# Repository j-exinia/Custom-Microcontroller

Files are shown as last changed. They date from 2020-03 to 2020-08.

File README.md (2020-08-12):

# Microcontroller Breakout Board

## Block Diagram

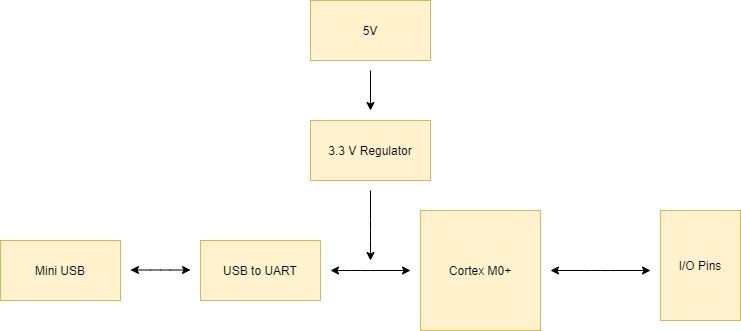
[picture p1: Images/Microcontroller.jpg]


## Peripherals 

### Microprocessor 

* [ARM Cortex M0+](https://www.mouser.com/datasheet/2/389/dm00613881-1799439.pdf)

### USB Mini Port

* [UJ2-MBH](https://www.mouser.com/datasheet/2/670/uj2-mbh-smt-1313286.pdf)

### USB to UART

* [FT230XS-R](https://www.mouser.com/datasheet/2/163/DS_FT230X-5395.pdf)

### Voltage Regulator

* [TPS77733DR](http://www.ti.com/lit/ds/symlink/tps777.pdf)

## Images
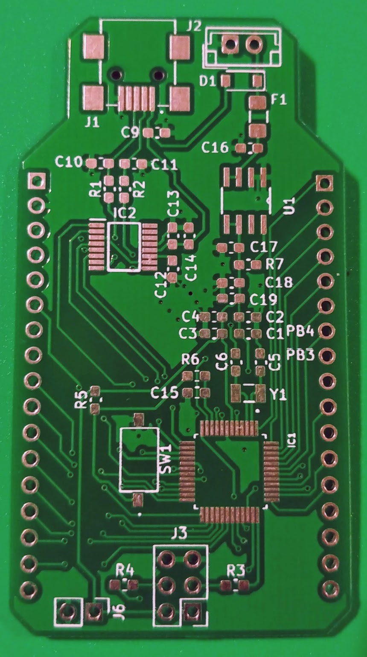
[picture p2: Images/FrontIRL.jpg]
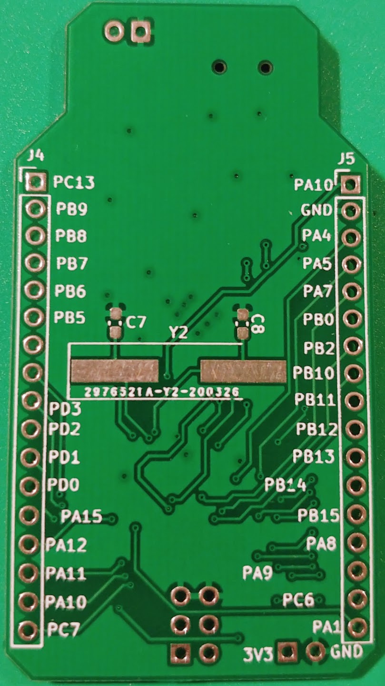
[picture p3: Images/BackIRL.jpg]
, 

## Designers

* **Jorge Exinia** - *PCB design* - [j-exinia](https://github.com/j-exinia)

### Built With

* [KiCad](https://kicad-pcb.org/) - The PCB design software used

### Errata

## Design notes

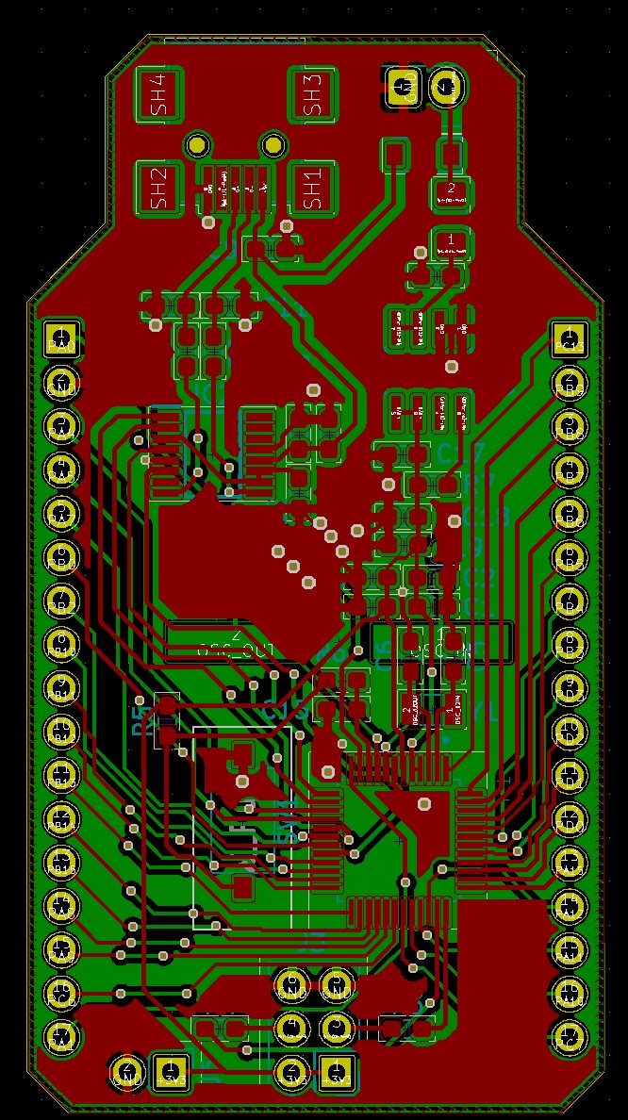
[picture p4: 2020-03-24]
Images/Combined.jpg

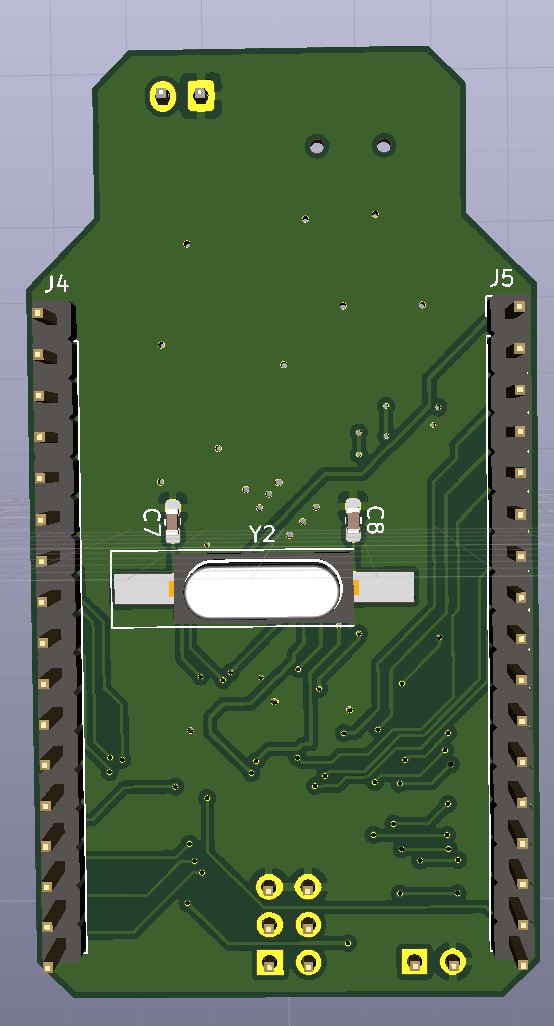
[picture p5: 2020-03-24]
Images/3dViewBottom.jpg

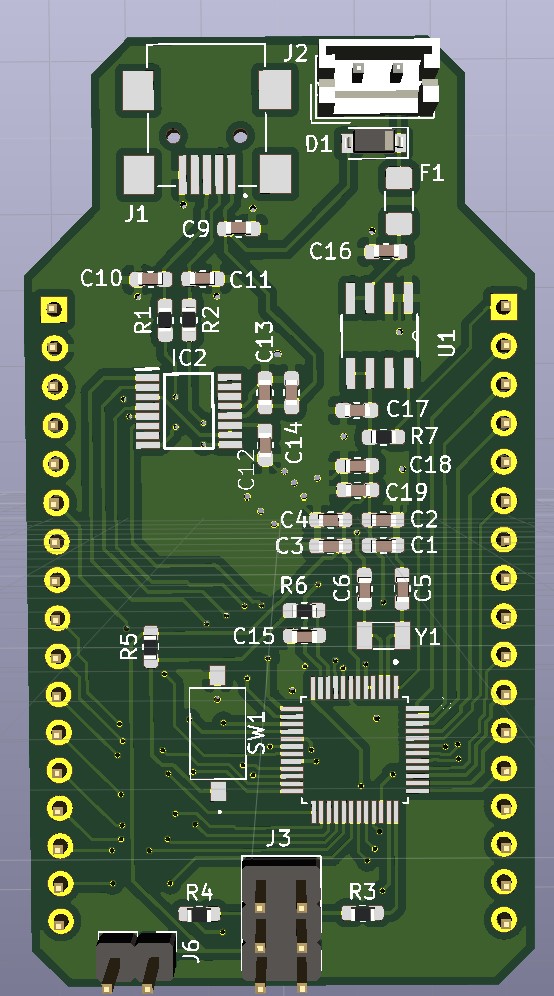
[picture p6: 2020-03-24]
Images/3dView.jpg

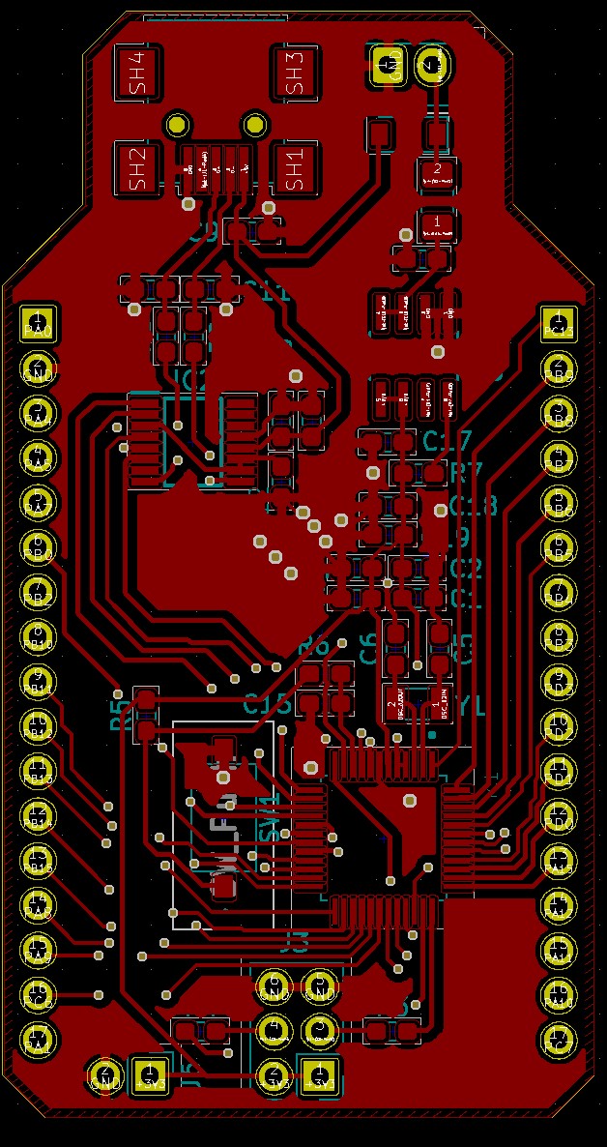
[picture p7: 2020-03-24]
Images/TopLayer .jpg

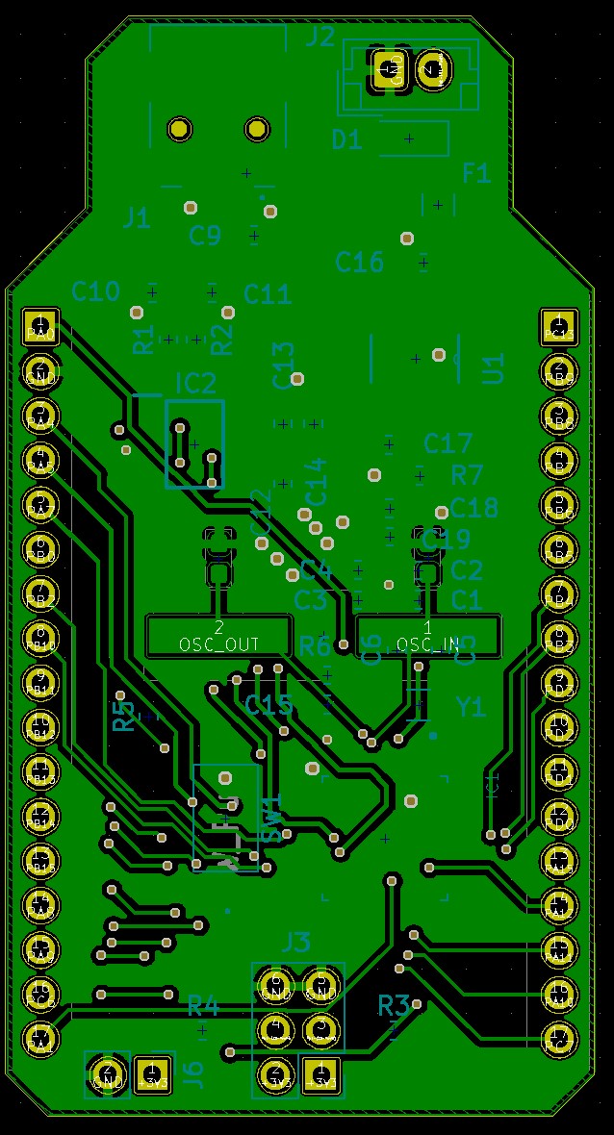
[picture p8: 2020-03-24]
Images/BottomLayer .jpg

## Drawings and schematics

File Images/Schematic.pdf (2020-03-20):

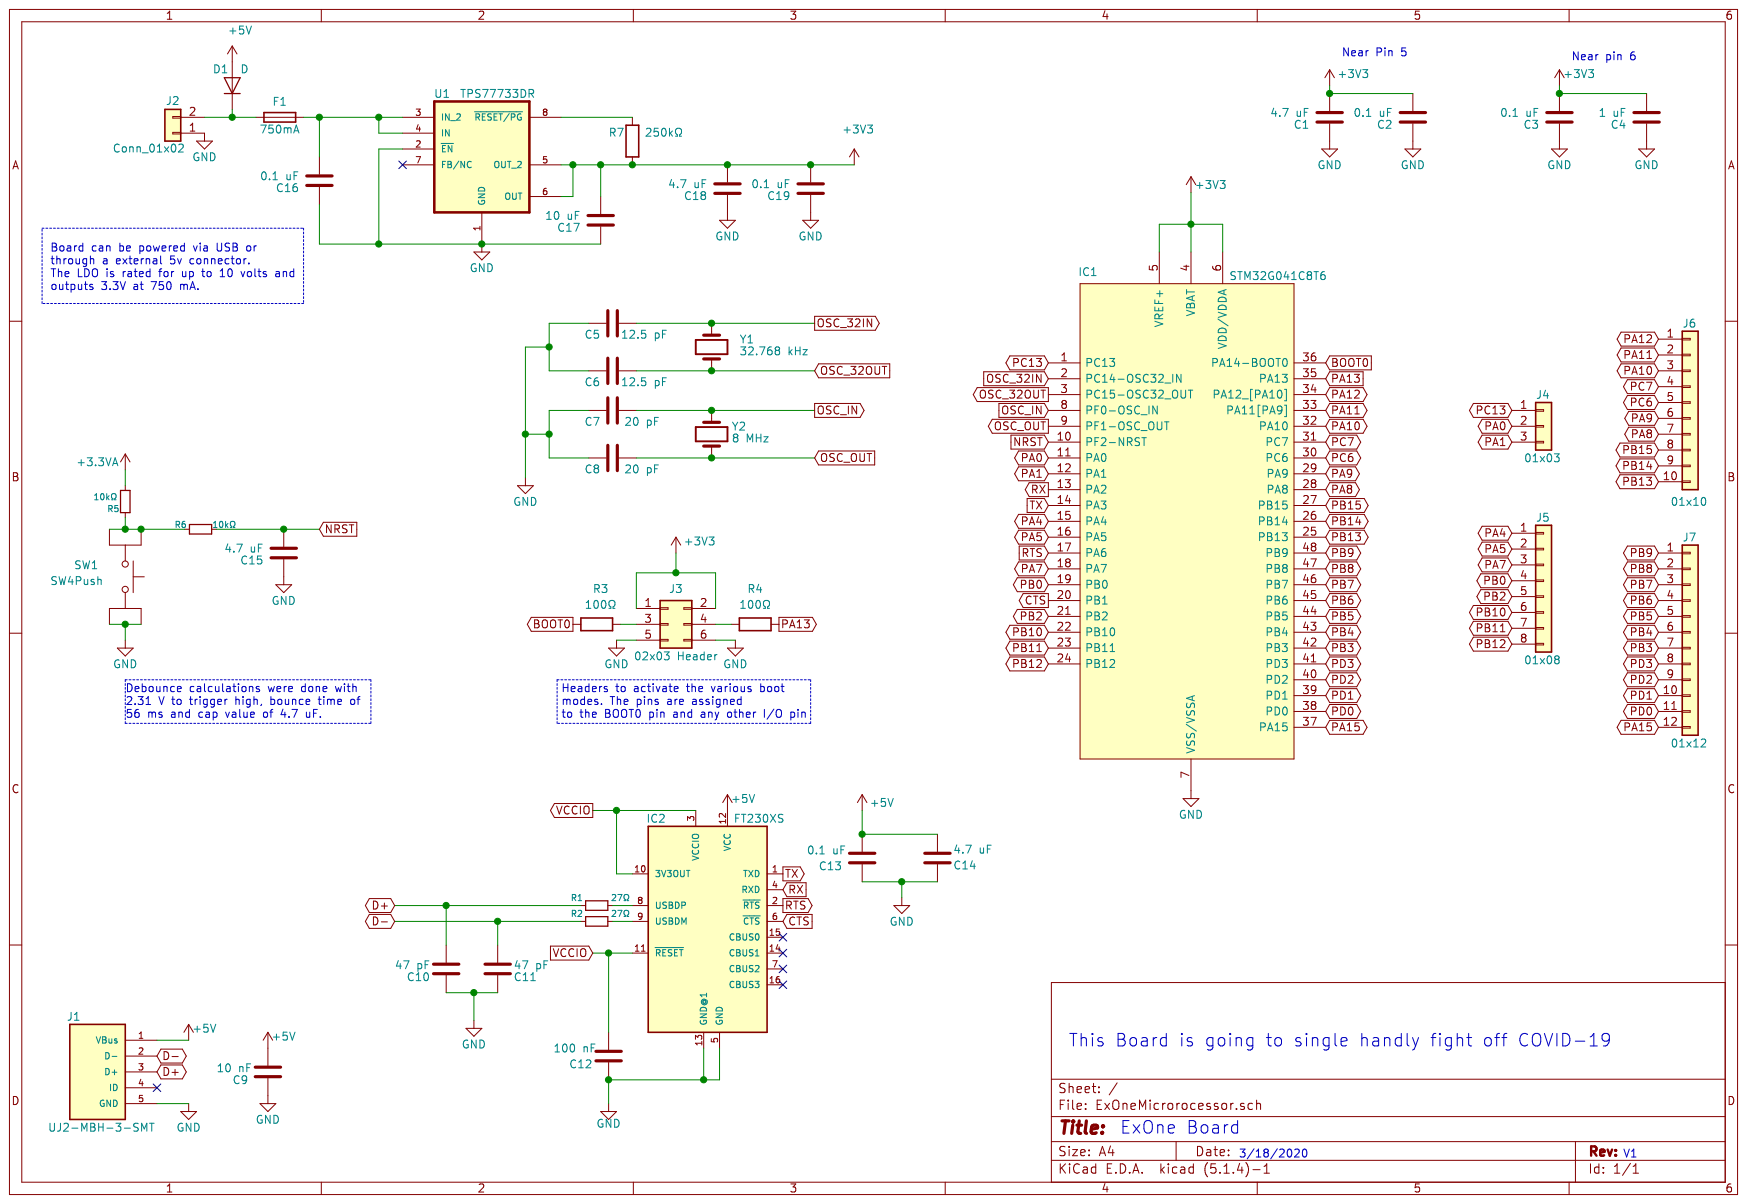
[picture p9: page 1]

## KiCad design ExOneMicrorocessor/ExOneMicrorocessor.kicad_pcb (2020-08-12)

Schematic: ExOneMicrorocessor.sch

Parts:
C1, C14, C15, C18: 4.7 uF; C_0603_1608Metric_Pad1.05x0.95mm_HandSolder
C2, C3, C12, C13, C16, C19: 0.1 uF; C_0603_1608Metric_Pad1.05x0.95mm_HandSolder
C4: 1 uF; C_0603_1608Metric_Pad1.05x0.95mm_HandSolder
C5, C6: 12.5 pF; C_0603_1608Metric_Pad1.05x0.95mm_HandSolder
C7, C8: 20 pF; C_0603_1608Metric_Pad1.05x0.95mm_HandSolder
C9: 0.01 uF; C_0603_1608Metric_Pad1.05x0.95mm_HandSolder
C10, C11: 47 pF; C_0603_1608Metric_Pad1.05x0.95mm_HandSolder
C17: 10 uF; C_0603_1608Metric_Pad1.05x0.95mm_HandSolder
D1: D; D_SOD-123
F1: 750mA; Fuse_1206_3216Metric_Pad1.42x1.75mm_HandSolder
IC1: STM32G041C8T6; STM32G041C8; Mouser Part Number 511-STM32G041C8T6
IC2: FT230XS
J1: UJ2-MBH-3-SMT; UJ2-MBH-SMT
J2: Conn_01x02; JST_EH_B2B-EH-A_1x02_P2.50mm_Vertical
J3: 02x03 Header; PinHeader_2x03_P2.54mm_Vertical
J4, J5: Conn_01x17; PinHeader_1x17_P2.54mm_Vertical
J6: Conn_01x02; PinHeader_1x02_P2.54mm_Vertical
R1, R2: 27Ω; R_0603_1608Metric_Pad1.05x0.95mm_HandSolder
R3, R4: 100Ω; R_0603_1608Metric_Pad1.05x0.95mm_HandSolder
R5, R6: 10kΩ; R_0603_1608Metric_Pad1.05x0.95mm_HandSolder
R7: 250kΩ; R_0603_1608Metric_Pad1.05x0.95mm_HandSolder
SW1: SW_Push; PTS636SM25SMTRLFS
U1: TPS77733DR; TPS77733
Y1: 32.768 kHz; Crystal_SMD_3215-2Pin_3.2x1.5mm
Y2: 8 MHz; Crystal_SMD_HC49-SD_HandSoldering

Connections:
3VLn: C12.1, IC2.3 (VCCIO), IC2.10 (3V3OUT), IC2.11 (~RESET~)
+3V3: C1.2, C2.2, C3.2, C4.2, C17.2, C18.2, C19.2, IC1.4 (VBAT), IC1.5 (VREF+), IC1.6 (VDD/VDDA), J3.1, J3.2, J6.1, R5.2, R7.1, U1.5 (OUT_2), U1.6 (OUT)
+5V: C9.1, C13.1, C14.2, D1.2 (A), IC2.12 (VCC), J1.1 (VBus)
BOOT0: IC1.36 (PA14-BOOT0), R3.2
CTS: IC1.20 (PB1), IC2.6 (~CTS~)
D+: C10.1, J1.3 (D+), R1.2
D-: C11.1, J1.2 (D-), R2.2
GND: C1.1, C2.1, C3.1, C4.1, C5.1, C6.1, C7.1, C8.1, C9.2, C10.2, C11.2, C12.2, C13.2, C14.1, C15.1, C16.1, C17.1, C18.1, C19.1, IC1.7 (VSS/VSSA), IC2.5 (GND), IC2.13 (GND@1), J1.5 (GND), J2.1, J3.5, J3.6, J5.2, J6.2, SW1.2, U1.1 (GND), U1.2 (~EN)
NRST: C15.2, IC1.10 (PF2-NRST), R6.2
unnamed: C16.2, F1.1, U1.3 (IN_2), U1.4 (IN)
unnamed: D1.1 (K), F1.2, J2.2
unnamed: IC2.8 (USBDP), R1.1
unnamed: IC2.9 (USBDM), R2.1
unnamed: J3.3, R3.1
unnamed: J3.4, R4.2
unnamed: R5.1, R6.1, SW1.1
unnamed: R7.2, U1.8 (~RESET/PG)
OSC_32IN: C5.2, IC1.2 (PC14-OSC32_IN), Y1.1
OSC_32OUT: C6.2, IC1.3 (PC15-OSC32_OUT), Y1.2
OSC_IN: C7.2, IC1.8 (PF0-OSC_IN), Y2.1
OSC_OUT: C8.2, IC1.9 (PF1-OSC_OUT), Y2.2
PA0: IC1.11 (PA0), J5.1
PA1: IC1.12 (PA1), J5.17
PA4: IC1.15 (PA4), J5.3
PA5: IC1.16 (PA5), J5.4
PA7: IC1.18 (PA7), J5.5
PA8: IC1.28 (PA8), J5.14
PA9: IC1.29 (PA9), J5.15
PA10: IC1.32 (PA10), J4.16
PA11: IC1.33 (PA11[PA9]), J4.15
PA12: IC1.34 (PA12_[PA10]), J4.14
PA13: IC1.35 (PA13), R4.1
PA15: IC1.37 (PA15), J4.13
PB0: IC1.19 (PB0), J5.6
PB2: IC1.21 (PB2), J5.7
PB3: IC1.42 (PB3), J4.8
PB4: IC1.43 (PB4), J4.7
PB5: IC1.44 (PB5), J4.6
PB6: IC1.45 (PB6), J4.5
PB7: IC1.46 (PB7), J4.4
PB8: IC1.47 (PB8), J4.3
PB9: IC1.48 (PB9), J4.2
PB10: IC1.22 (PB10), J5.8
PB11: IC1.23 (PB11), J5.9
PB12: IC1.24 (PB12), J5.10
PB13: IC1.25 (PB13), J5.11
PB14: IC1.26 (PB14), J5.12
PB15: IC1.27 (PB15), J5.13
PC6: IC1.30 (PC6), J5.16
PC7: IC1.31 (PC7), J4.17
PC13: IC1.1 (PC13), J4.1
PD0: IC1.38 (PD0), J4.12
PD1: IC1.39 (PD1), J4.11
PD2: IC1.40 (PD2), J4.10
PD3: IC1.41 (PD3), J4.9
RTS: IC1.17 (PA6), IC2.2 (~RTS~)
RX: IC1.13 (PA2), IC2.4 (RXD)
TX: IC1.14 (PA3), IC2.1 (TXD)

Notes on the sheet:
3/18/2020
This Board is going to single handly fight off COVID-19
ExOne Board
Near Pin 5
Near pin 6
Debounce calculations were done with 2.31 V to trigger high, bounce time of 56 ms and cap value of 4.7 uF.
Board can be powered via USB or through a external 5v connector. The LDO is rated for up to 10 volts and outputs 3.3V at 750 mA.
Headers to activate the various boot modes. The pins are assigned to the BOOT0 pin and any other I/O pin

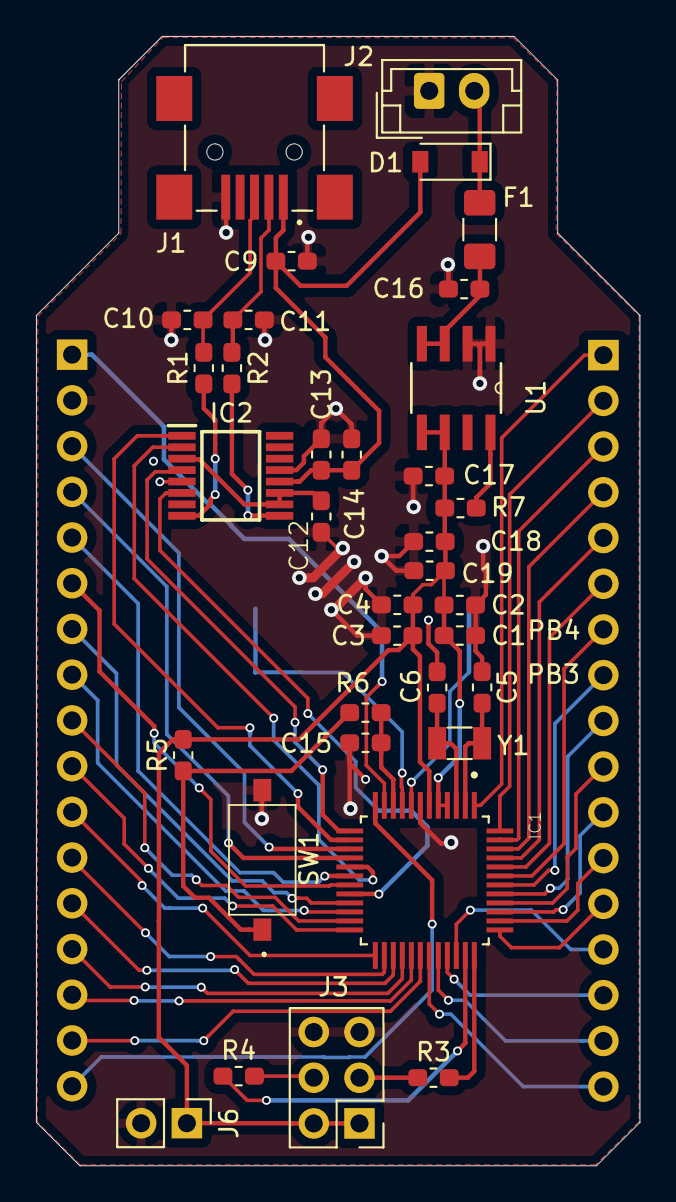
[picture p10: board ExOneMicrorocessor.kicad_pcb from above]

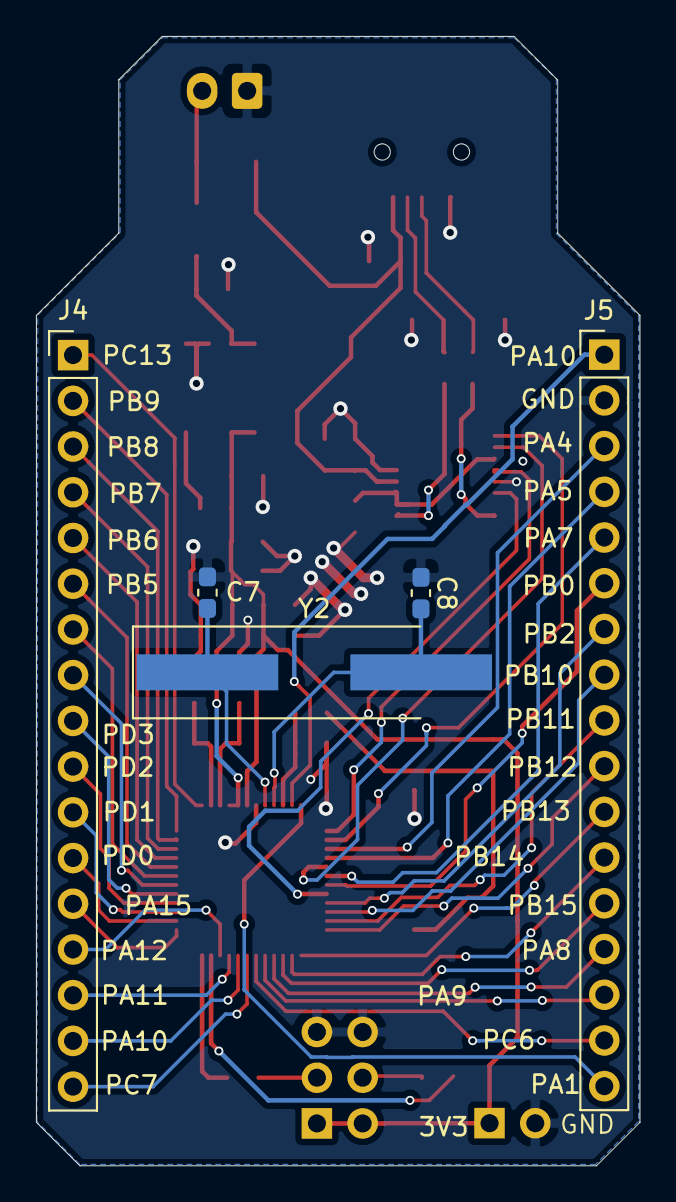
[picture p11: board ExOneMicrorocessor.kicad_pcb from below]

Board: 2 copper layers, 33.5 x 62.7 mm, 40 parts (5 on the bottom side), 58 nets.

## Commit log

2020-03-18 Added library folder with library for parts
    [ExOneMicrorocessor.kicad_pcb, ExOneMicrorocessor.sch]
2020-03-18 Started work on schematic
    [ExOneMicrorocessor.sch]
2020-03-18 finished the schematic for the microP
    [ExOneMicrorocessor.sch]
2020-03-18 nvm fixed some directions on some pins
    [ExOneMicrorocessor.sch]
2020-03-19 Updated Schematic
    Updated net names
    Added various notes explaning the design further
    Changed the LDO IC
    [ExOneMicrorocessor.sch]
2020-03-19 Just forgot to save it in the schema
    [ExOneMicrorocessor.sch]
2020-03-19 Fixed schematic
    Change bypass caps on the IC
    added pull up resistors on the switch
    removed some comments
    [ExOneMicrorocessor.sch]
2020-03-20 started work on the PCB layout
    [ExOneMicrorocessor.kicad_pcb, ExOneMicrorocessor.sch]
2020-03-22 started PCB LAyout
    [ExOneMicrorocessor.kicad_pcb, ExOneMicrorocessor.sch]
2020-03-24 Added Photos of the PCB
2020-03-24 FInished work on pcb , added some pads for 3v3 and gnd
    [ExOneMicrorocessor.kicad_pcb, ExOneMicrorocessor.sch]
2020-03-24 Added Gerber files and drill files
    [ExOneMicrorocessor-B_Adhes.gbr, ExOneMicrorocessor-B_CrtYd.gbr, ExOneMicrorocessor-B_Cu.gbr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]
2020-08-12 push for T
    [ExOneMicrorocessor-B_Adhes.gbr, ExOneMicrorocessor-B_CrtYd.gbr, ExOneMicrorocessor-B_Cu.gbr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]
2020-08-12 made prod files JLC complimant
    [ExOneMicrorocessor.sch]
2020-08-12 JLC files
    [ExOneMicrorocessor-B_Adhes.gbr, ExOneMicrorocessor-B_CrtYd.gbr, ExOneMicrorocessor-B_Cu.gbr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]
